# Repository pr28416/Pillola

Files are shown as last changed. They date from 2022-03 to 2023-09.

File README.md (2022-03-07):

# Pillola - Demo Code

Smart pill dispenser. Built with Arduino. Developed in C++. This code may not be duplicated or distributed elsewhere in any manner by any party. All rights to the code are reserved for Pranav Ramesh, who developed this code.

Pillola was a venture launched by Pranav Ramesh, Eitan Gotian, Anushka Mukhopadhyay, Verena Gonzalez, and Jamal Mathew during the 2021 Jerome Fisher Management & Technology Summer Institute at the University of Pennsylvania. Pillola is centered around distributing control over medication management among seniors, staff, and software, and is intended for usage in senior living facilities.

CAD renders were developed by Pranav Ramesh and Eitan Gotian. All rights to the designs are reserved for Pranav Ramesh and Eitan Gotian.

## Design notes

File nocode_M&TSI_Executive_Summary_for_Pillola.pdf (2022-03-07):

# Pillola

Management & Technology Summer Institute (M&TSI) 2021

University of Pennsylvania

Anushka Mukhopadhyay, Ethan ”Eitan” Gotian, Jamal Matthew,

Pranav Ramesh, Verena Gonzalez

LATEX Documentation by Pranav Ramesh

July 2021

## Executive Summary

Medication Management and Pill Security

Medication management and pill security are prevalent issues in senior health today. Unfortunately, seniors

are one of the greatest victims of medication theft in independent living facilities. They are often targeted

by caregivers, nurses, or other staff who swap out vital medication either for self-use or to sell to others for

profit. This results in residents taking the wrong medication or receiving their medication in inadequate

amounts, both of which are very detrimental to their well-being. According to a recent review of state reports

of drug thefts from the School of Nursing at the University of Minnesota, ”the average resident lost 45 doses

of medication due to theft,” which can put countless individuals in harm’s way (Mir).

Furthermore, many seniors take several medications at once, and managing these different medication reg-

imens can often be confusing. As a result, they may forget to take their medication, lose track of their

medication schedule, or accidentally take the wrong dosage. Consequently, irregularities in their pill con-

sumption occur, increasing the risk of serious medical ailments such as accelerated organ failure, uncontrolled

bleeding, and hallucinations, which can all be fatal. In fact, ”medication non-adherence is responsible for 30

percent of hospital readmissions” (The Danger of Forgetting or Taking the Wrong Medication). So far, the

only solution to this problem has been 24/7 monitoring of patients by the caregivers in the facilities. How-

ever, a study of the State Regulatory Review conducted by the National Center for Assisted Living in 2013

reported that ”63% of the staff at [Assisted Living Facilities] offer help and administration of prescription

medications to residents”, indicating that while there are many staff members actively tailoring to seniors’

medical needs, such requirements are still not being sufficiently met (Medication Management).

In our interview with Kristofer Munch, the executive director of the Alura by Inspired Living senior liv-

ing facility in Rockledge, Florida, our team gained insight into how caregivers administer medication to

patients. While caregivers go to the senior’s room at the designated times to deliver their medication, they

may often find themselves overwhelmed when helping seniors with their medication, throwing pill delivery

timings into jeopardy. To mitigate this issue, the state of Florida allows caregivers to administer medication

within a two-hour time frame of the prescribed dosage time; however, this results in a frequent pattern of

inconsistent medication consumption.

Introducing Pillola

Pillola is the reinvention of the pill bottle that aims to tackle these two issues of pill security and medication

management. It reminds the user (senior) to take their medication with audio alerts and mobile notifications,

dispenses the correct doses at scheduled times, and provides secure access with fingerprint identification. To

gain access to the pill chambers for refilling (or emergency use), the senior or respective caregiver must enter

a four-digit passcode on the keypad [Appendix 1]. This reduces the risk of pills being swapped or tampered

with by others.

In addition, Pillola highly prioritizes the automated monitoring and analysis of pill consumption by users.

With the Pillola app, both seniors and their loved ones will be able to track every aspect of pill usage,

including but not limited to whether the pill was taken and at what time [Appendix 4]. The app records this

information in detail by tracking user input from the keypad sent through the NodeMCU. These features

make the process by which seniors take their medications as prescribed easier, relieve caregivers and family

members that seniors are doing so, and reassure independent senior living facilities that their residents’

medications are safe and secure.

Other automatic pill dispensers exist in the pharmaceutical manufacturing industry and pill bottle mar-

kets, such as the Hero pill dispenser, MedaCube, and MedMinder; however, none of these dispensers are

compact, connects seniors and their loved ones with an easy-to-use interface, or maintain high-level security

to protect a user’s pills. Pillola is the only dispenser that maintains the familiarity of a pill bottle while

incorporating the previously listed features. Its small size [Appendix 6] allows for product storage in various

locations, from the user’s purse to their kitchen countertop. Pillola is also equipped with a unique dispensing

mechanism that operates a 180-degree custom dial indexer to accept one pill at a time from an overhead

container. Such a method enables Pillola to avoid the need to presort pills as conventional pill organizers do

[Appendix 3]. In addition, this unique mechanism allows Pillola to mitigate the possibility of dispensing too

many pills and makes it easier to keep track of exact pill outtake.

Who is Pillola for?

Pillola specifically targets senior citizens who want better ways to track their medication and family members

(sons, daughters, caregivers) that are concerned about their loved ones following their medication schedule.

According to an analysis by the National Center for Health Statistics, ”...the number of Americans using

five or more prescription drugs increased 70 percent over the past 10 years” (Prescription drug use on the

rise in the United States).

Additionally, the greatest percentage of consumers of prescription medication are those over the age of

65, where ”40 percent of the nation’s seniors used five or more prescription drugs in a one-month period”

(Prescription drug use on the rise in the United States). Thus, at a time when prescription drug use is rising,

and the population of Americans 65 and older has increased by 34.2% in the last decade - according to 2019

population estimates published by the United States Census Bureau in June 2020 - the future of consumer

demand for Pillola is very opportunistic (65 and Older Population Grows Rapidly as Baby Boomers Age).

The Pillola App and Hardware Configuration

Pillola’s software user interface is designed to be simple enough for both seniors and their loved ones or

caregivers to use. When a senior (user) receives their Pillola, they will configure fingerprint authentication

settings, set a four-digit passcode, and download the app on their phone to receive notifications [Appendix

5]. Once they receive their pills, they can open the pill bottle using the fingerprint scanner and pour their

pills into the top of the bottle [Appendix 2].

The dispensing mechanism handles distributing the designated dose using our custom dial indexer [Ap-

pendix 3]. The setup process is complete once the time at which the senior needs to take their pills and the

dosage is inputted using the keypad. For seniors who are not comfortable with mobile phone technology or

do not have their phone with them, the Pillola device emits a sound using a piezo buzzer. In addition, the

user can customize the number of pill types dispensed by Pillola and colors for the outer shell [Appendix 1].

Reaching Seniors, Caregivers, and Families

To reach our intended consumer base, Pillola will advertise using search engine optimization (SEO), cost-

per-click, and targeted promotions through social networking platforms. SEO will be customized to appeal

to seniors, assisted living facility caregivers, and concerned family members whose web searches indicate

a proactive interest in senior medication assistance. Ideally, our product will appear on the user’s screen

after searching for something to do with the issues we are solving. Additionally, with a well-designed price

per-click advertising model, we will be able to effectively promote our product on sites whose content lines

up with similar issues (i.e., a blog about pill consumption or an article with steps to help one remember to take one’s medication), and lead people to our website. Our target market predominantly uses Facebook,

and many advertisements can be launched on this platform. Once users are directed to our website, they

can easily explore our features and order directly online.

Our target market predominantly uses Facebook, and many advertisements can be launched on this plat-

form. Once users are directed to our website, they can easily explore our features and order directly online.

Our team will also reach out to the heads of several senior living facilities and make deals with them to have

Pillola be a standard product used by their residents. The next step would be to get Pillola approved by

public health officials from government institutions like the Food and Drug Administration (FDA) so that

consumer confidence is achieved and federal safety requirements are met. Lastly, once a stable customer

base is acquired, we plan to mass-produce and sell the product in-store chains such as CVS, Walmart, and

Walgreens.

Scalability and Revenue with Living Facilities and Domestic Purchases

To sustain the competitive advantage of Pillola’s product development and distribution operations over

time, sample Pillola bottles would be dispersed to senior facility homes through customer feedback loops

that will receive and value user input. Such streamlined insights from seniors and caregivers would inform

Pillola about how different degrees of consumer satisfaction can improve its business model and competitive

strategy over time. The value of the pill bottle would also be calculated through factoring in key predictor

variables, including but not limited to product sales data, customer reviews, and competitive analytics to

gauge the strength of other companies with slightly differentiated products.

Pillola’s business model is centered around the proposed pill bottle’s mass production and third-party retail

distribution. This would be done with a steadfast approach that commits toward ensuring both a frequent

usage of the product and increased market share from existing Pillola users influencing new users to pur-

chase the products through word-of-mouth and reviews. We can reflect the unit economics of this model by

implementing the following equation:

Gross Profit = ((# seniors) · ((# bottles per senior) − (COGS per senior)) · (revenue split))

– ((# ads) · (ad click-through rate) · (cost-per-click of ad))

− (marketing expenses)

We categorize the user of a Pillola product as a senior in an independent living facility. While they or a

facility may pay for the product, the seniors who are using the product are the fundamental revenue drivers.

Revenue is calculated by the number of pill bottles purchased per senior, multiplied by the number of se-

niors that use Pillola. A revenue split is included in our model since third-party retailers will eventually distribute Pillola; any online purchases, however, will allow Pillola to benefit from the entire selling profit of

the product. The cost of goods sold initially plays a role in our model’s unit costs. However, as adoption of

the Pillola pill bottle increases and the bottle nears mass production, it will eventually decrease, increasing

the ratio of revenue to costs. This is because Pillola bottles are 3D-printed, and 3D-printing technology has

reduced economies of scale because of reliance on the availability of printers and filaments, which are not

entirely expended per individual bottle production.

Pillola will also be advertised through prominent search engines such as Google and marketing represen-

tatives who discuss the benefits of Pillola with caregivers who are taking care of seniors. Costs associated

with marketing and promotional efforts contribute to the customer acquisition value because they are in-

curred after taking actions such as meeting with caregivers to promote the product to new users. As Pillola

becomes more widespread, we expect that new customers will be attracted by our effective advertising mod-

els in addition to word of mouth and successful usage at senior assisted-living facilities, thereby decreasing

the costs contributed by the customer acquisition values and increasing its potential to scale into a widely

profitable business.

## References

[1] ”The | Danger | of | Forgetting | or | Taking | the | Wrong | Medication.” | Assisting | Hands,
17 | Dec. | 2019, | www.assistinghands.com/8/illinois/chicagoland-naperville/blog/

forgetting-or-taking-the-wrong-medication/. Accessed 29 July 2021.

[2] ”Medication | Management.” | Senior | Care, | www.seniorcare.com/assisted-living/resources/

services-provided/medication-management/. Accessed 29 July 2021.

[3] Mir, Heather Vincent. ”Drug Theft in Assisted-Living Homes.” The Oldish Proactive Aging, 15 July

2019, www.theoldish.com/drug-theft-in-assisted-living-homes/. Accessed 29 July 2021.

[4] ”Prescription drug use on the rise in the United States.” APHA, www.thenationshealth.org/content/

40/8/E37/. Accessed 29 July 2021.

[5] ”65 and Older Population Grows Rapidly as Baby Boomers Age.” United States Census Bureau,

25 June 2020, www.census.gov/newsroom/press-releases/2020/65-older-population-grows.html.

Accessed 29 July 2021.

## Appendix 1

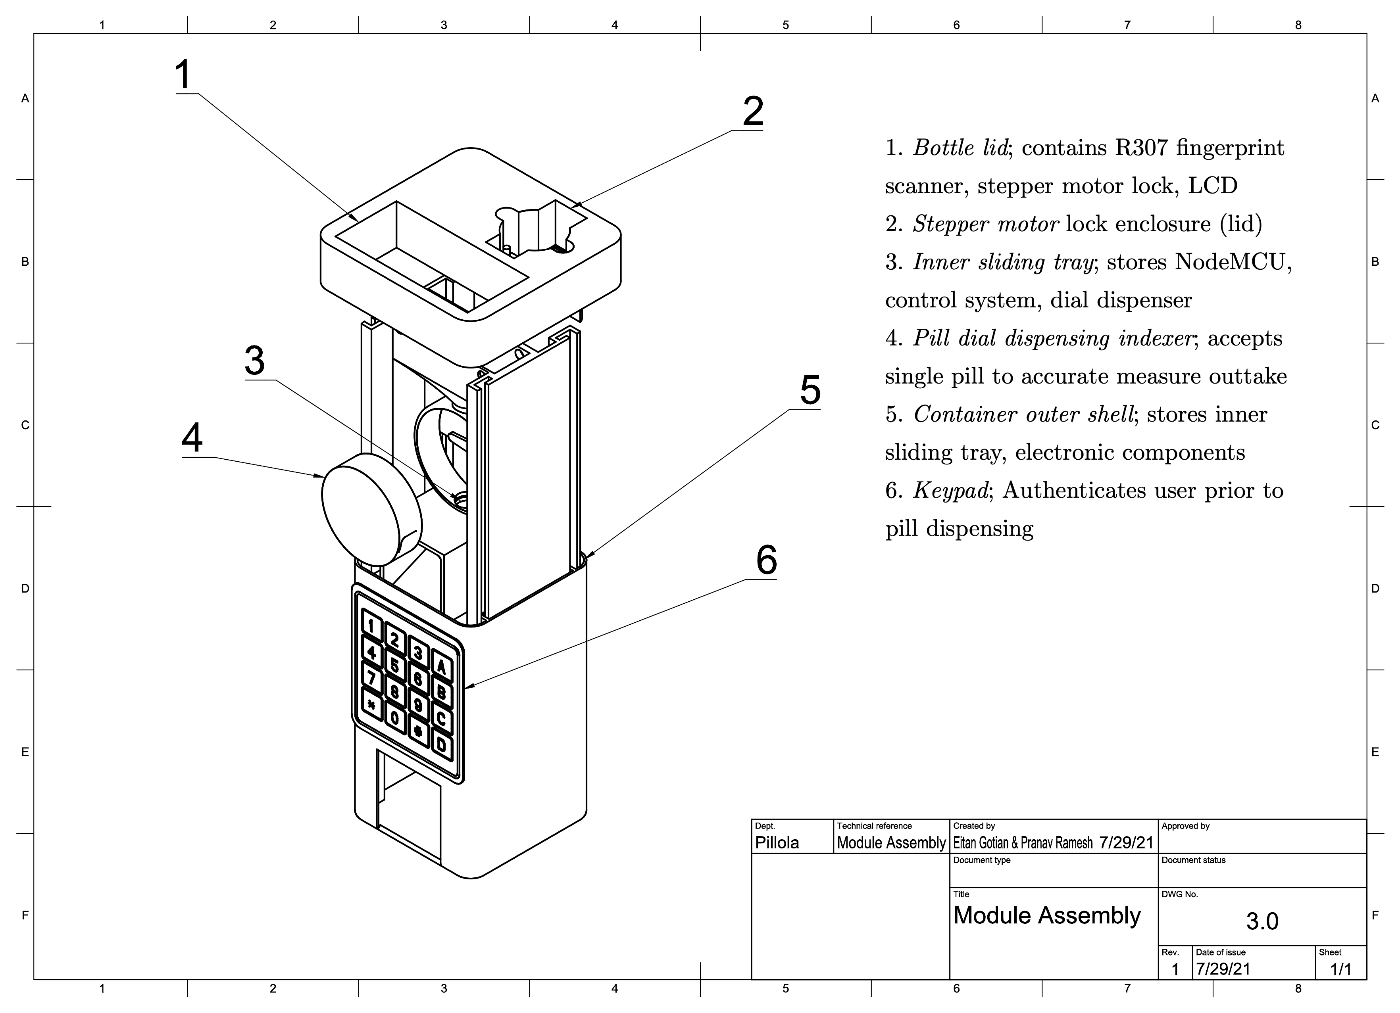
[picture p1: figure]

Figure 1: Line drawing of the key components of the module highlighting the feature and mechanisms for

pill dispensing and the shelling mechanism. Created by Pranav Ramesh and Eitan Gotian with Autodesk

Fusion 360.

## Appendix 2

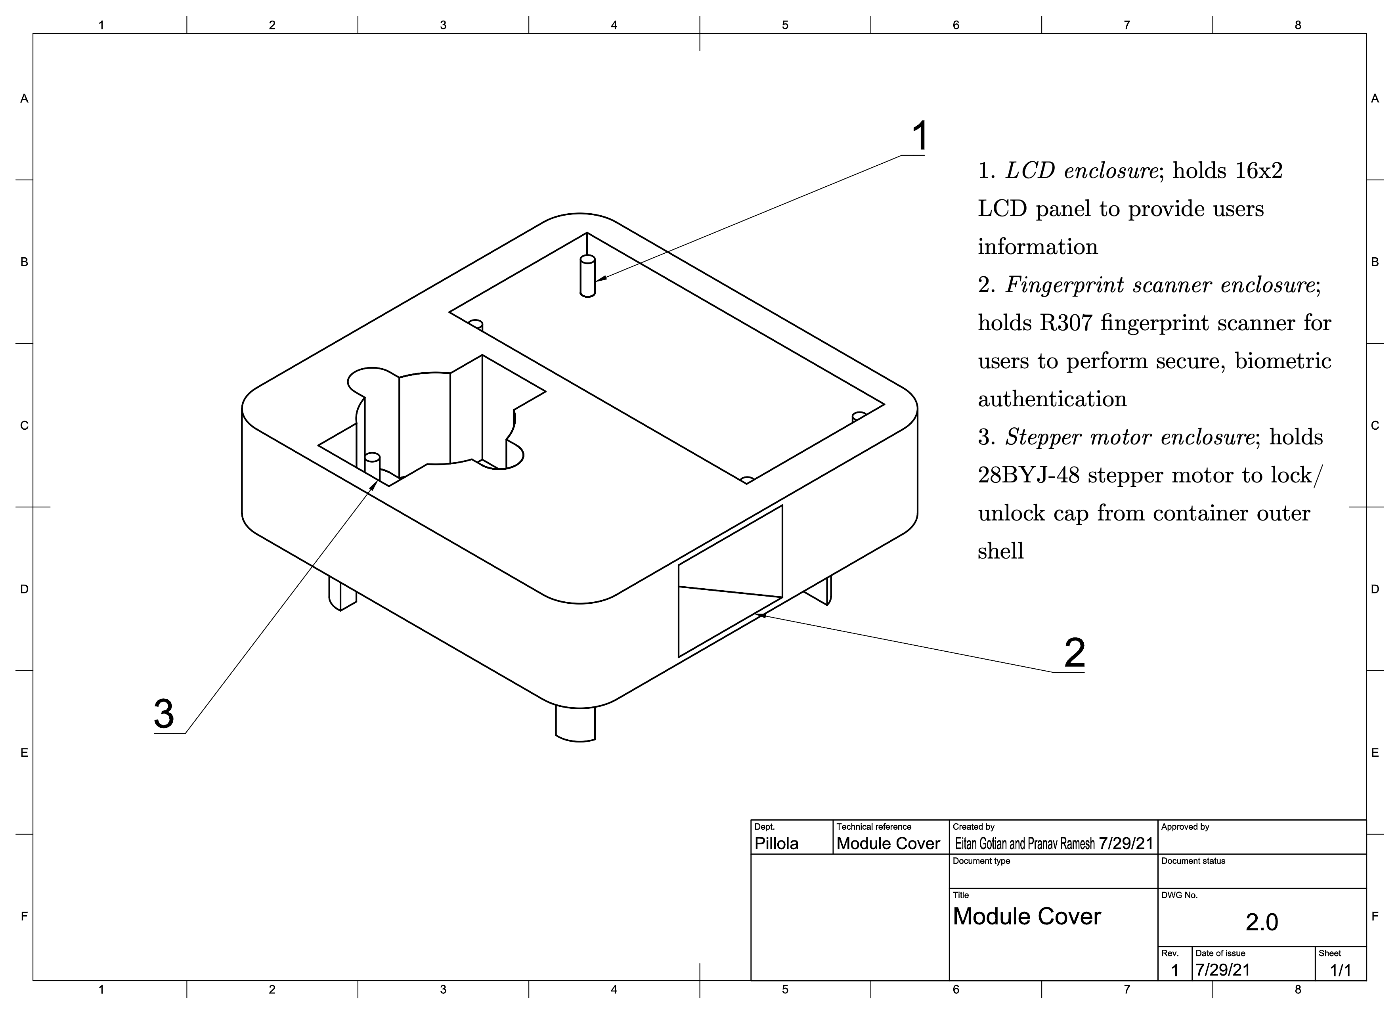
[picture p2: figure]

Figure 2: Line drawing of the module cover highlighting the cavities for the embedded electronic components.

Created by Pranav Ramesh and Eitan Gotian with Autodesk Fusion 360.

## Appendix 3

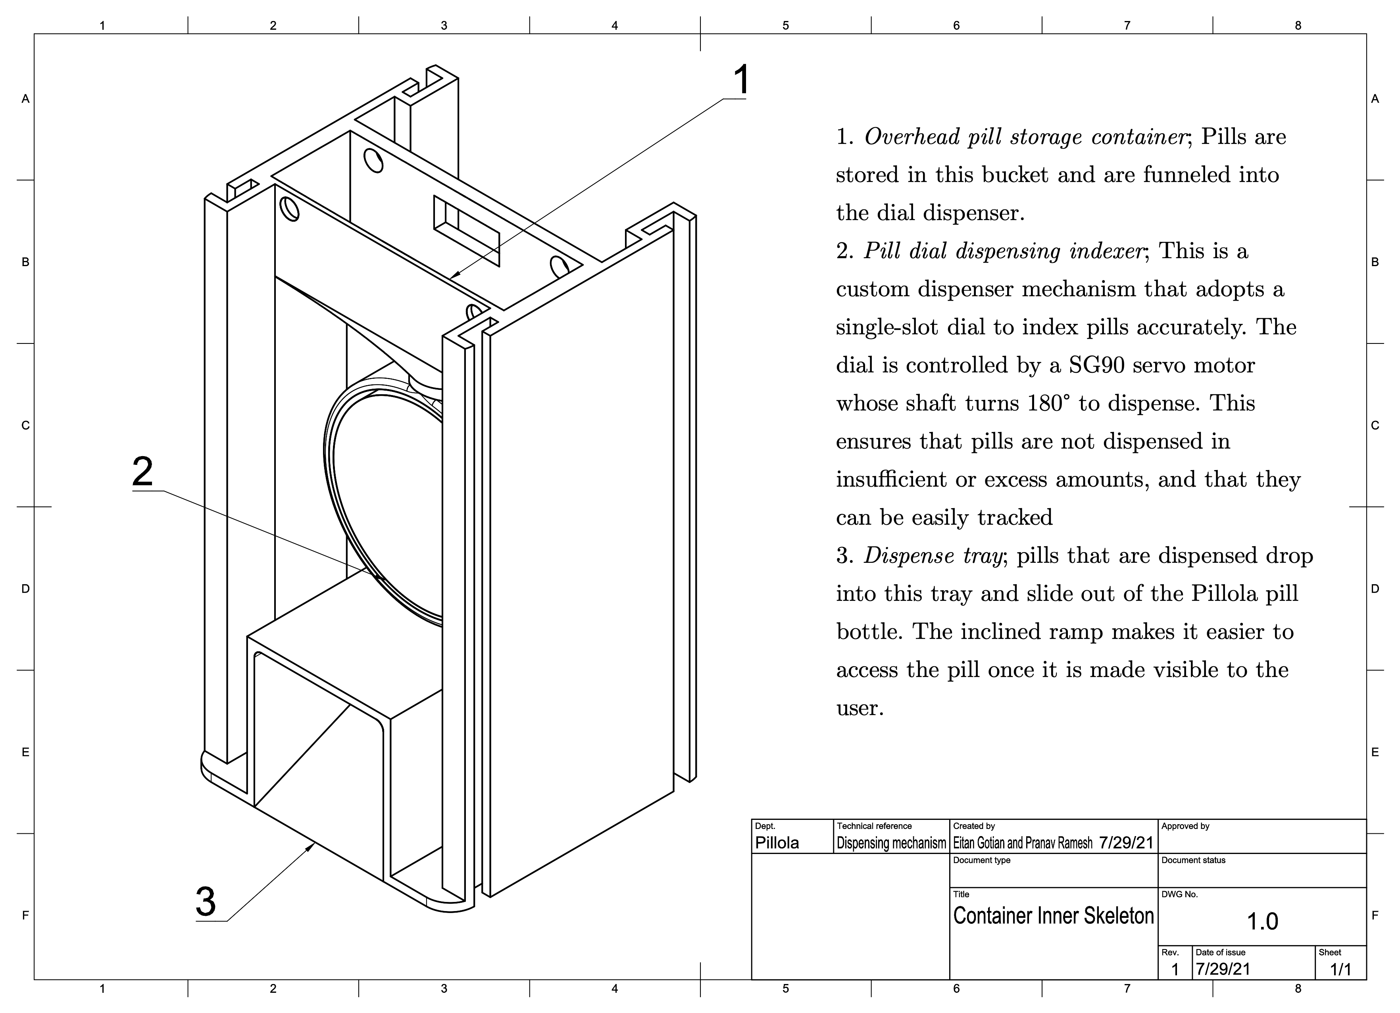
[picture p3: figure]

Figure 3: Line drawing of the dispensing mechanism highlighting the dial indexer and pill storage container.

Container Inner Skeleton. Created by Pranav Ramesh and Eitan Gotian with Autodesk Fusion 360.

## Appendix 4

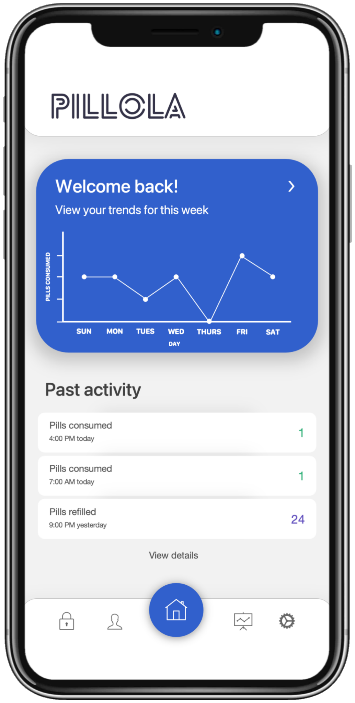
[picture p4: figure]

Figure 4: Screenshot of the home screen interface for the Pillola client iOS app. Includes consumption trends

and past activity.

## Appendix 5

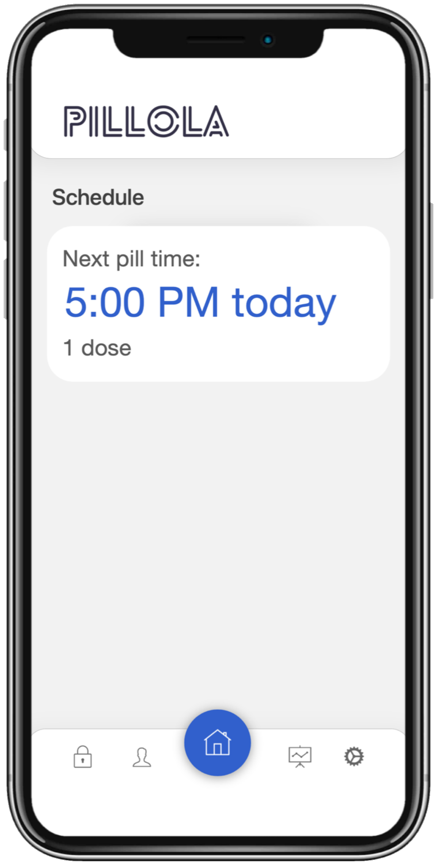
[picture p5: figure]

Figure 5: Screenshot of the schedule notification interface for the Pillola client iOS app. Includes upcoming

pill consumption times in the day.

## Appendix 6

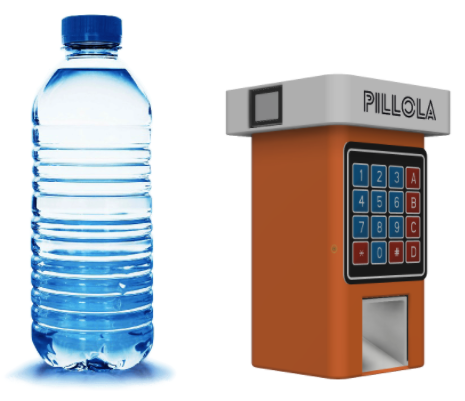
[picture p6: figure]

Figure 6: Side-by-side comparison of a 16-oz. bottle to the Pillola pill bottle. The comparison is indicative

of Pillola’s small form factor.

## Appendix 7

Item | Accuracy | Description
Sensor Accuracy | 97.5% | Based on testing and recording data.
Alarm accuracy | 100% | As long as the NodeMUC maintains a network connection.
App notification accuracy | 100% | As long as the NodeMCU maintains a network connection and the user enables notification settings.
Proposed Battery Life | N/A | In the future we plan to use a lithium rechargeable battery that will power the model for 3-5 days. We arrived at this number by determining the average voltage the module needs.
Proposed motor life | N/A | Servo motor will last approximately 5 years. This number was calculated based on the average number of dispenses per day and consumption schedule length.

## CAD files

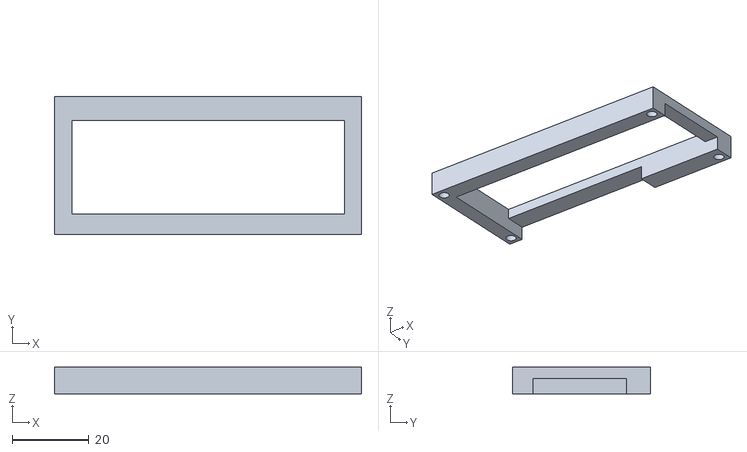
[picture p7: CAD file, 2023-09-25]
Pillola 3DP Files/[new] LCD Rect Cover v2.stl
80.0 x 36.0 x 7.00

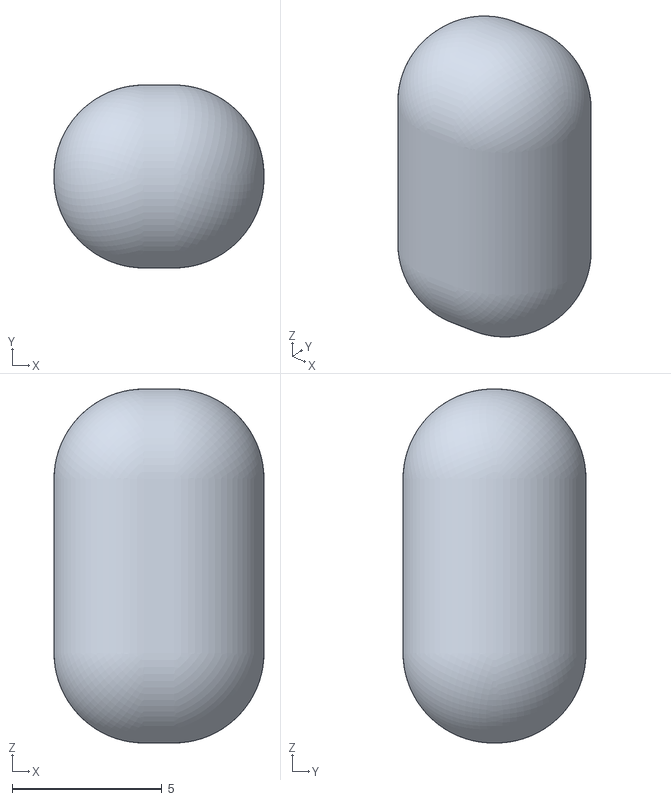
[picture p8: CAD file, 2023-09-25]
Pillola 3DP Files/pill3.stl
7.00 x 6.10 x 11.8

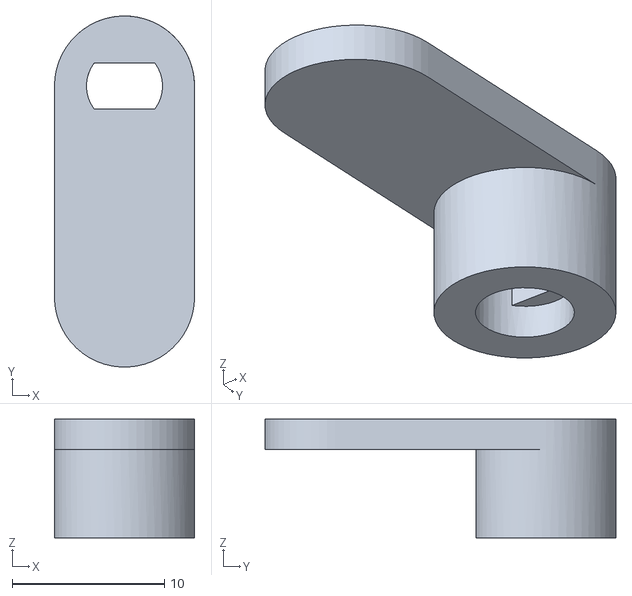
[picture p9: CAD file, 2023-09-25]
Pillola 3DP Files/[test] Lock test v20.stl
9.20 x 23.0 x 7.80

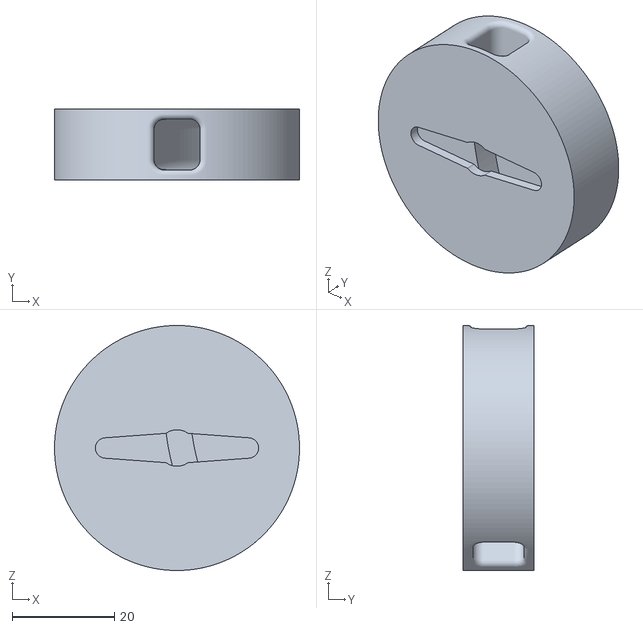
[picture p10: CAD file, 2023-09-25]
Pillola 3DP Files/[new better] Dial Dispenser optimized v6.stl
48.0 x 14.0 x 48.0

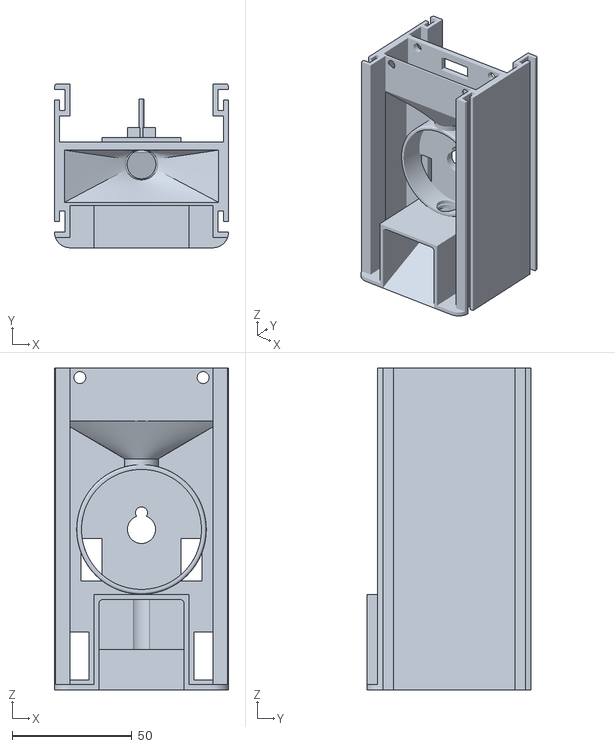
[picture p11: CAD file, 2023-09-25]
Pillola 3DP Files/[new] Container inner skeleton v63.stl
72.6 x 68.2 x 134.2

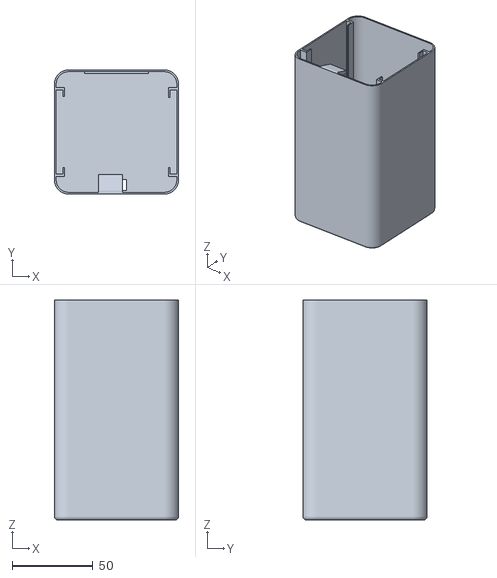
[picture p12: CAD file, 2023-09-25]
Pillola 3DP Files/[new] Container outer shell v58.stl
77.0 x 77.0 x 136.4

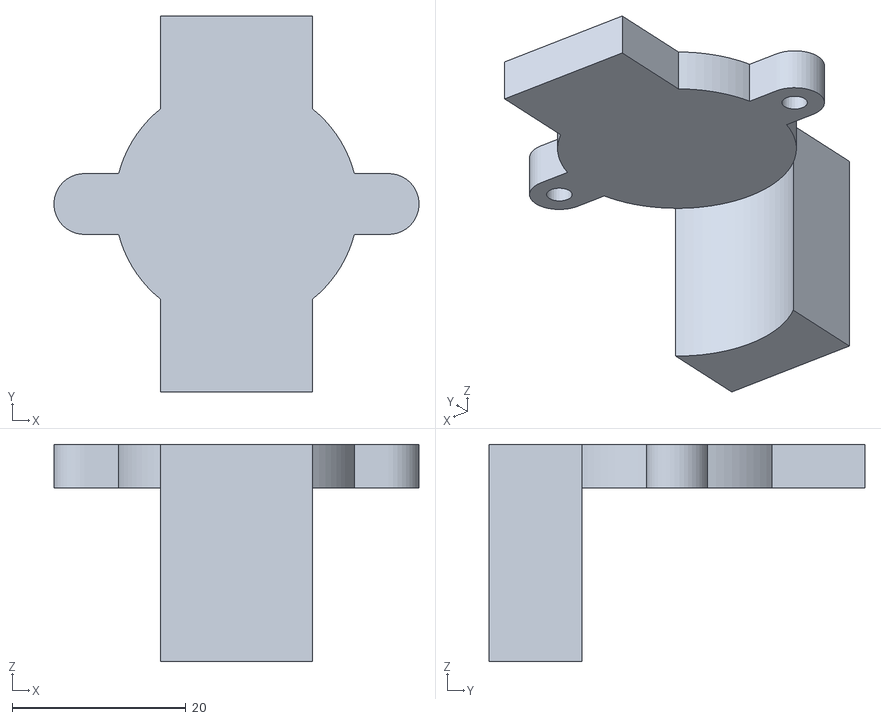
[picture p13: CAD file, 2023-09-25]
Pillola 3DP Files/[new] Stepper Motor Cover v7.stl
42.0 x 43.2 x 25.0

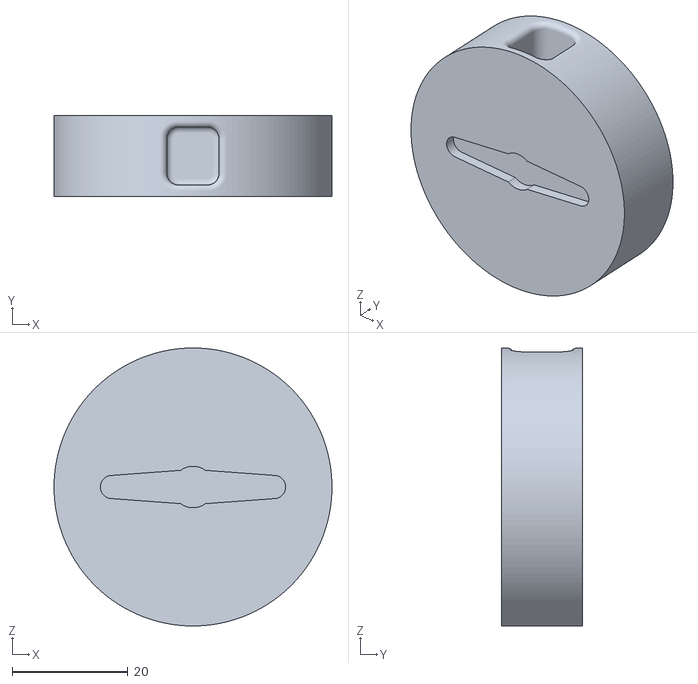
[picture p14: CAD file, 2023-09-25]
Pillola 3DP Files/[new] Dial Dispenser v17.stl
48.0 x 14.0 x 48.0

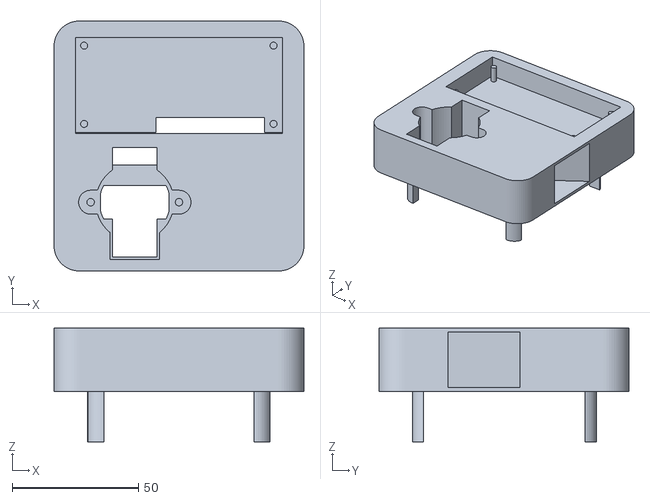
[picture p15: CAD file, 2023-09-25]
Pillola 3DP Files/[new better] LCD Cap v20.stl
99.0 x 99.0 x 45.0

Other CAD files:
Pillola 3DP Files/[new] Dial Dispenser v17.f3z
Pillola Exports/LCD_ASM v1.f3d
Pillola Exports/LCD_backlight v1.f3d
Pillola Exports/R307 v4.f3d
Pillola Exports/Servo v1 v9.f3d
Pillola Exports/[new] Dial Dispenser v17.f3z
Pillola Exports/[new] LCD Rect Cover v2.f3z
Pillola Exports/[new] Stepper Motor Cover v7.f3d
Pillola Exports/keypad-16KeyMembrane v11.f3d
Pillola Exports/pill v1.f3d

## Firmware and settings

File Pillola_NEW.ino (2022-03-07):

// Pillola - Smart pill dispenser
// © 2021 Pranav Ramesh. All rights reserved.
// This code may not be duplicated or distributed
// elsewhere in any manner by any party. All rights to
// the code are attributed to Pranav Ramesh.

#include <Adafruit_Fingerprint.h>
#include <LiquidCrystal.h>
#include <Keypad.h>
#include <Servo.h>
LiquidCrystal lcd = LiquidCrystal(8,9,13,12,11,10);

char hexaKeys[4][4] = {
  {'1', '2', '3', 'A'},
  {'4', '5', '6', 'B'},
  {'7', '8', '9', 'C'},
  {'*', '0', '#', 'D'}
};

byte rowPins[4] = {A0,A1,A2,A3};
byte colPins[4] = {4,5,6,7};
Keypad customKeypad = Keypad(makeKeymap(hexaKeys), rowPins, colPins, 4, 4);

Servo dialServo;

SoftwareSerial mySerial(2,3);
Adafruit_Fingerprint finger = Adafruit_Fingerprint(&mySerial);

int getFingerprintID() {
  
  uint8_t p = finger.getImage();
  if (p != FINGERPRINT_OK)  return -1;

  p = finger.image2Tz();
  if (p != FINGERPRINT_OK)  return -1;

  p = finger.fingerFastSearch();
  if (p != FINGERPRINT_OK)  return -1;

  // found a match!
  Serial.print("Found ID #"); Serial.print(finger.fingerID);
  Serial.print(" with confidence of "); Serial.println(finger.confidence);
  return finger.fingerID;
}

void setup() {
  Serial.begin(9600);
  lcd.begin(16, 2);
  dialServo.attach(A5, 300, 2500);
  //  dialServo.attach(A4);
  dialServo.write(4);
  finger.begin(57600);
  delay(5);
  if (finger.verifyPassword()) {
    Serial.println("Found fingerprint sensor");
  } else {
    Serial.println("Did not find fingerprint sensor");
    lcd.print("! No fingerprint");
    lcd.setCursor(0, 1); lcd.print("sensor found.");
    while (1) {
      delay(1);
    }
  }

  finger.getTemplateCount();

  if (finger.templateCount == 0) {
    Serial.print("Sensor doesn't contain any fingerprint data. Please run the 'enroll' example.");
  }
  else {
    Serial.println("Waiting for valid finger...");
    Serial.print("Sensor contains "); Serial.print(finger.templateCount); Serial.println(" templates");
  }
}

int i = 0;
char passcode[4] = {'1', '3', '7', '9'};
char key;

boolean authenticateKeypad(String message) {
  lcd.clear();
  lcd.setCursor(0, 0); lcd.print(message);
  lcd.setCursor(0, 1); lcd.print("Passcode: ");
  short digit = 0;
  char givenCode[4];
  bool correct;
  do {
    key = customKeypad.getKey();
    if (key >= 48 && key < 58 && digit < 4) {
      givenCode[digit] = key;
      Serial.print("Digit "); Serial.print(digit);
      Serial.print(":"); Serial.println(key);
      correct = givenCode[digit] == passcode[digit++];
      lcd.print(key);
    } else if (key == 'B' && digit >= 0) {
      digit = max(0, digit - 1);
      lcd.setCursor(10 + digit, 1);
      lcd.print(" "); lcd.setCursor(10 + digit, 1);
      givenCode[digit] = '\0';
    } else if (key == 'C' && digit == 4) {
      if (correct) {
        lcd.clear();
        lcd.setCursor(0, 0); lcd.print("Correct");
        lcd.setCursor(0, 1); lcd.print("passcode.");
        delay(1500); lcd.clear();
      } else {
        lcd.clear();
        lcd.setCursor(0, 0); lcd.print("Incorrect");
        lcd.setCursor(0, 1); lcd.print("passcode.");
        delay(1500); lcd.clear();
      }
      return correct;
    }
  } while (true);
}

void loop() {
  lcd.setCursor(0, 0);
  key = customKeypad.getKey();

  // No action
  if (!key) {
    lcd.print("Pillola");
  }

  // A
  if (key == 'A') {
    if (authenticateKeypad("Dispense pill")) {
      dialServo.write(180);
      delay(1500);
      dialServo.write(4);
    }
  }

  // B
  else if (key == 'B') {
    lcd.print("Looking for");
    lcd.setCursor(0, 1); lcd.print("fingerprint...");
    int id = getFingerprintID();
    while (id <= 0) {
      key = customKeypad.getKey();
      if (key == 'D') {
        lcd.clear();
        lcd.setCursor(0, 0); lcd.print("Canceled.");
        delay(1500); lcd.clear();
        break;
      }
      id = getFingerprintID();
    }
    if (id > 0) {
      lcd.clear();
      lcd.setCursor(0, 0); lcd.print("Successfully");
      lcd.setCursor(0, 1); lcd.print("authenticated");
      delay(1500); dialServo.write(180);
      delay(1500); dialServo.write(4);
      lcd.clear();

    }
  }

  // C
  else if (key == 'C') {
    lcd.print("C");
    lcd.setCursor(0, 1); lcd.print("Not assigned.");
    delay(1000); lcd.clear();
  }

  // D
  else if (key == 'D') {
    lcd.print("D");
    lcd.setCursor(0, 1); lcd.print("Not assigned.");
    delay(1000); lcd.clear();
  }
}
